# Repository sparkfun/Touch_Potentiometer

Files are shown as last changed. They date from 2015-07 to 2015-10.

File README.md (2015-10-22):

SparkFun Touch_Potentiometer
===================

SparkFun Touch Potentiometer

[*SparkFun Touch Potentiometer (PRT-13144)*](https://www.sparkfun.com/products/13144)

The Touch Potentiometer is a collaboration between DanJulioDesigns and SparkFun Electronics. The Touch Pot allows you to easily integrate a slide potentiometer into any project that requires such an interface, such as the volume control on a stereo. 

Repository Contents
-------------------

* **/Documentation** - Data sheets, additional product information
* **/Hardware** - Eagle design files (.brd, .sch)
* **/Production** - Production panel files (.brd)

Documentation
--------------
* **[Hookup Guide](https://learn.sparkfun.com/tutorials/touch-potentiometer-hookup-guide)** - Basic hookup guide for the SparkFun Touch Potentiometer.
* **[SparkFun Fritzing repo](https://github.com/sparkfun/Fritzing_Parts)** - Fritzing diagrams for SparkFun products.
* **[SparkFun 3D Model repo](https://github.com/sparkfun/3D_Models)** - 3D models of SparkFun products. 

Product Versions
----------------
* [*SEN-13144*](https://www.sparkfun.com/products/13144)

Version History
---------------

* [V_1.0.0](https://github.com/sparkfun/SparkFun_BME280_Breakout_Board/tree/V_1.0.0) - Public release.

License Information
-------------------

This product is _**open source**_! 

Please review the LICENSE.md file for license information. 

If you have any questions or concerns on licensing, please contact techsupport@sparkfun.com.

Distributed as-is; no warranty is given.

- Your friends at SparkFun.

_<COLLABORATION CREDIT>_

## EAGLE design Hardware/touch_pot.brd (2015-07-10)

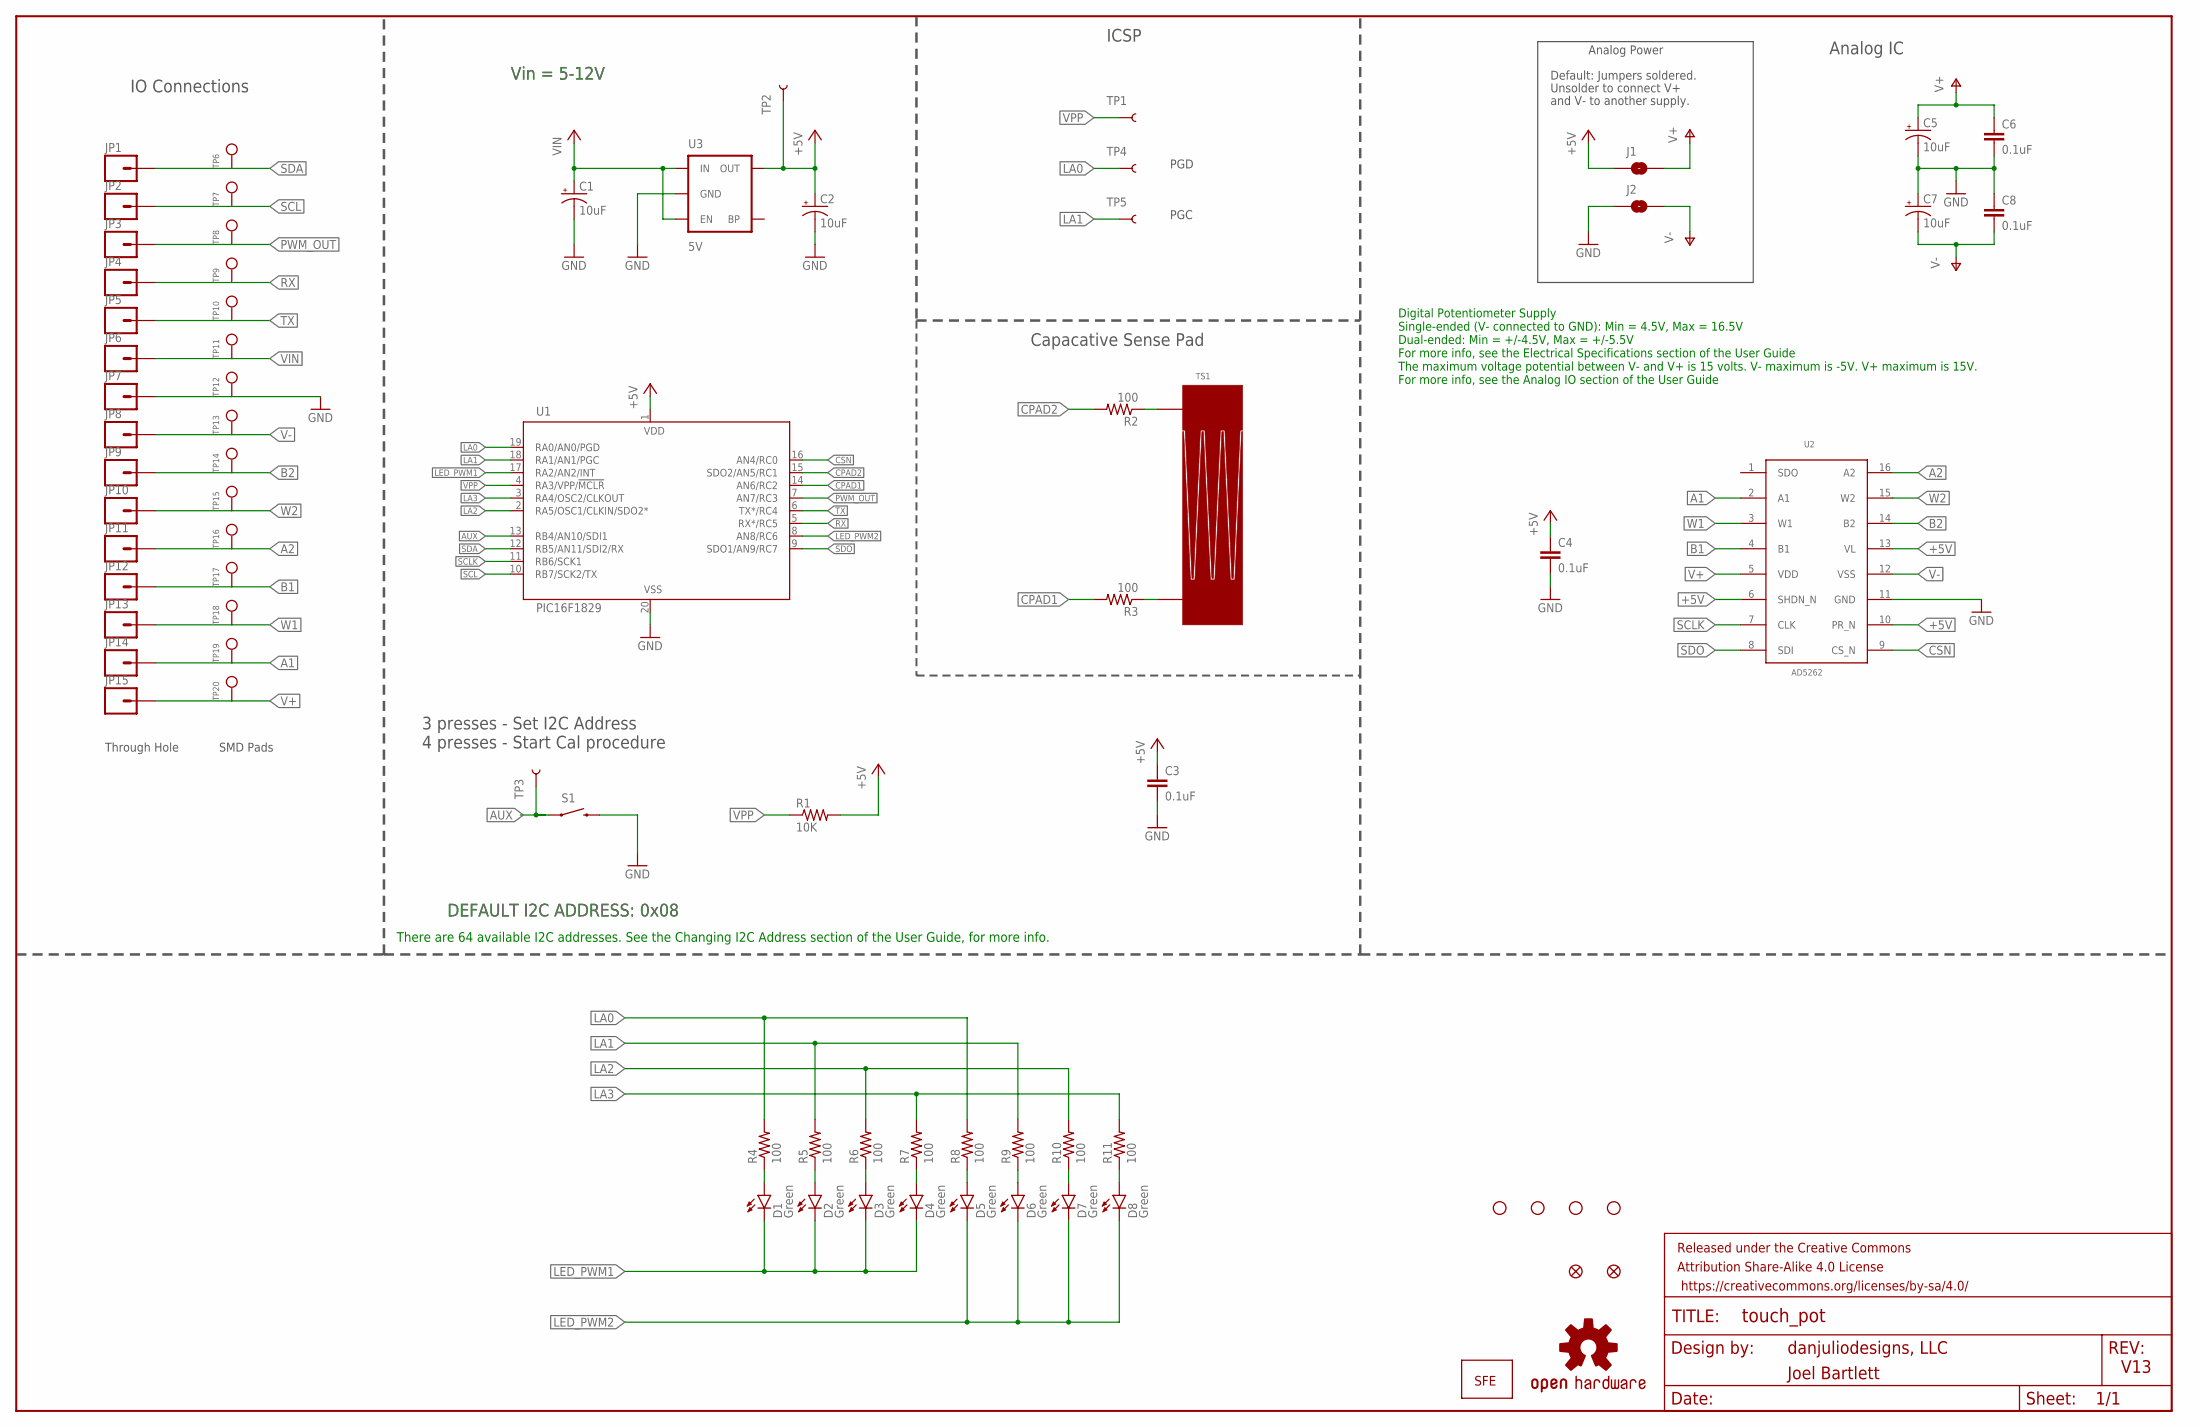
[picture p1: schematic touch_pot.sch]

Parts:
C1, C2, C5, C7: 10uF; EIA3216
C3, C4, C6, C8: 0.1uF; 0603-CAP
D1, D2, D3, D4, D5, D6, D7, D8: Green; LED-1206-BOTTOM
FID1, FID2: FIDUCIAL1X2; FIDUCIAL-1X2
FRAME3: FRAME-LEDGER; CREATIVE_COMMONS
J1, J2: SJCLOSED; SJ_2S
JP1, JP2, JP3, JP4, JP5, JP6, JP7, JP8, JP9, JP10, JP11, JP12, JP13, JP14, JP15: M01SMDNS; 1X01NS
R1: 10K; 0603-RES
R2, R3, R4, R5, R6, R7, R8, R9, R10, R11: 100; 0603-RES
S1: SWITCH-MOMENTARY-2SMD; TACTILE-SWITCH-SMD
STANDOFF1, STANDOFF2, STANDOFF3, STANDOFF4: STAND-OFFTIGHT; STAND-OFF-TIGHT
TP1, TP2, TP3, TP4, TP5: TEST-POINT3X4; PAD.03X.04
TP6, TP7, TP8, TP9, TP10, TP11, TP12, TP13, TP14, TP15, TP16, TP17, TP18, TP19, TP20: SINGLE_PADSMD; 2MM_SMD_PAD
TS1: 2CH_LINEAR_TOUCH; 2CH_48MM_LINEAR_TOUCH
U1: PIC16F1829; SSOP20
U2: AD5262; SSOP16
U3: 5V; SOT23-5
U$4: OSHW-LOGOM; OSHW-LOGO-M
U$5: SFE_LOGO_NAME_WEB; SFE-NEW-WEBLOGO

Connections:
+5V: C2.A (+), C3.1, C4.1, J1.1, R1.2, TP2.P$1, U1.1 (VDD), U2.6 (SHDN_N), U2.10 (PR_N), U2.13 (VL), U3.5 (OUT)
A1: JP14.1, TP19.P$1, U2.2 (A1)
A2: JP11.1, TP16.P$1, U2.16 (A2)
AUX: S1.1, TP3.P$1, U1.13 (RB4/AN10/SDI1)
B1: JP12.1, TP17.P$1, U2.4 (B1)
B2: JP9.1, TP14.P$1, U2.14 (B2)
CPAD1: R3.2, U1.14 (AN6/RC2)
CPAD2: R2.2, U1.15 (SDO2/AN5/RC1)
CSN: U1.16 (AN4/RC0), U2.9 (CS_N)
GND: C1.C (-), C2.C (-), C3.2, C4.2, C5.C (-), C6.2, C7.A (+), C8.1, J2.1, JP7.1, S1.3 (2), TP12.P$1, U1.20 (VSS), U2.11 (GND), U3.2 (GND)
LA0: R4.2, R8.2, TP4.P$1, U1.19 (RA0/AN0/PGD)
LA1: R5.2, R9.2, TP5.P$1, U1.18 (RA1/AN1/PGC)
LA2: R6.2, R10.2, U1.2 (RA5/OSC1/CLKIN/SDO2*)
LA3: R7.2, R11.2, U1.3 (RA4/OSC2/CLKOUT)
LED_PWM1: D1.C, D2.C, D3.C, D4.C, U1.17 (RA2/AN2/INT)
LED_PWM2: D5.C, D6.C, D7.C, D8.C, U1.8 (AN8/RC6)
unnamed: D1.A, R4.1
unnamed: D2.A, R5.1
unnamed: D3.A, R6.1
unnamed: D4.A, R7.1
unnamed: D5.A, R8.1
unnamed: D6.A, R9.1
unnamed: D7.A, R10.1
unnamed: D8.A, R11.1
unnamed: R2.1, TS1.P$2
unnamed: R3.1, TS1.P$1
PWM_OUT: JP3.1, TP8.P$1, U1.7 (AN7/RC3)
RX: JP4.1, TP9.P$1, U1.5 (RX*/RC5)
SCL: JP2.1, TP7.P$1, U1.10 (RB7/SCK2/TX)
SCLK: U1.11 (RB6/SCK1), U2.7 (CLK)
SDA: JP1.1, TP6.P$1, U1.12 (RB5/AN11/SDI2/RX)
SDO: U1.9 (SDO1/AN9/RC7), U2.8 (SDI)
TX: JP5.1, TP10.P$1, U1.6 (TX*/RC4)
V+: C5.A (+), C6.1, J1.2, JP15.1, TP20.P$1, U2.5 (VDD)
V-: C7.C (-), C8.2, J2.2, JP8.1, TP13.P$1, U2.12 (VSS)
VIN: C1.A (+), JP6.1, TP11.P$1, U3.1 (IN), U3.3 (EN)
VPP: R1.1, TP1.P$1, U1.4 (RA3/VPP/!MCLR)
W1: JP13.1, TP18.P$1, U2.3 (W1)
W2: JP10.1, TP15.P$1, U2.15 (W2)

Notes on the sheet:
danjuliodesigns, LLC
V13
3 presses - Set I2C Address 4 presses - Start Cal procedure
IO Connections
ICSP
Analog Power
Default: Jumpers soldered.
PGD
PGC
Unsolder to connect V+
and V- to another supply.
Through Hole
SMD Pads
Joel Bartlett
Analog IC
Vin = 5-12V
DEFAULT I2C ADDRESS: 0x08
Digital Potentiometer Supply Single-ended (V- connected to GND): Min = 4.5V, Max = 16.5V Dual-ended: Min = +/-4.5V, Max = +/-5.5V For more info, see the Electrical Specifications section of the User Guide The maximum voltage potential between V- and V+ is 15 volts. V- maximum is -5V. V+ maximum is 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
Capacative Sense Pad
There are 64 available I2C addresses. See the Changing I2C Address section of the User Guide, for more info.

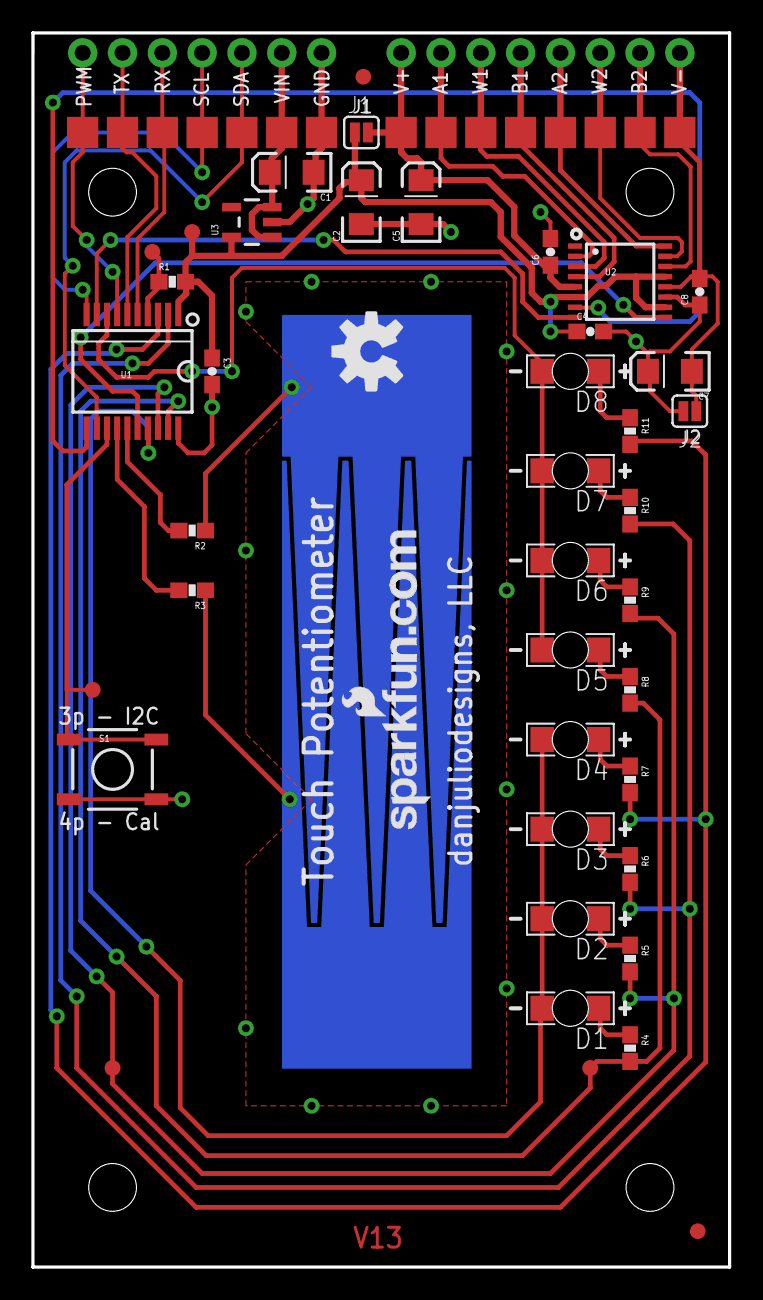
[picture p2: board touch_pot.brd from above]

Board: 2 copper layers, 44.5 x 78.7 mm, 78 parts (1 on the bottom side), 39 nets.

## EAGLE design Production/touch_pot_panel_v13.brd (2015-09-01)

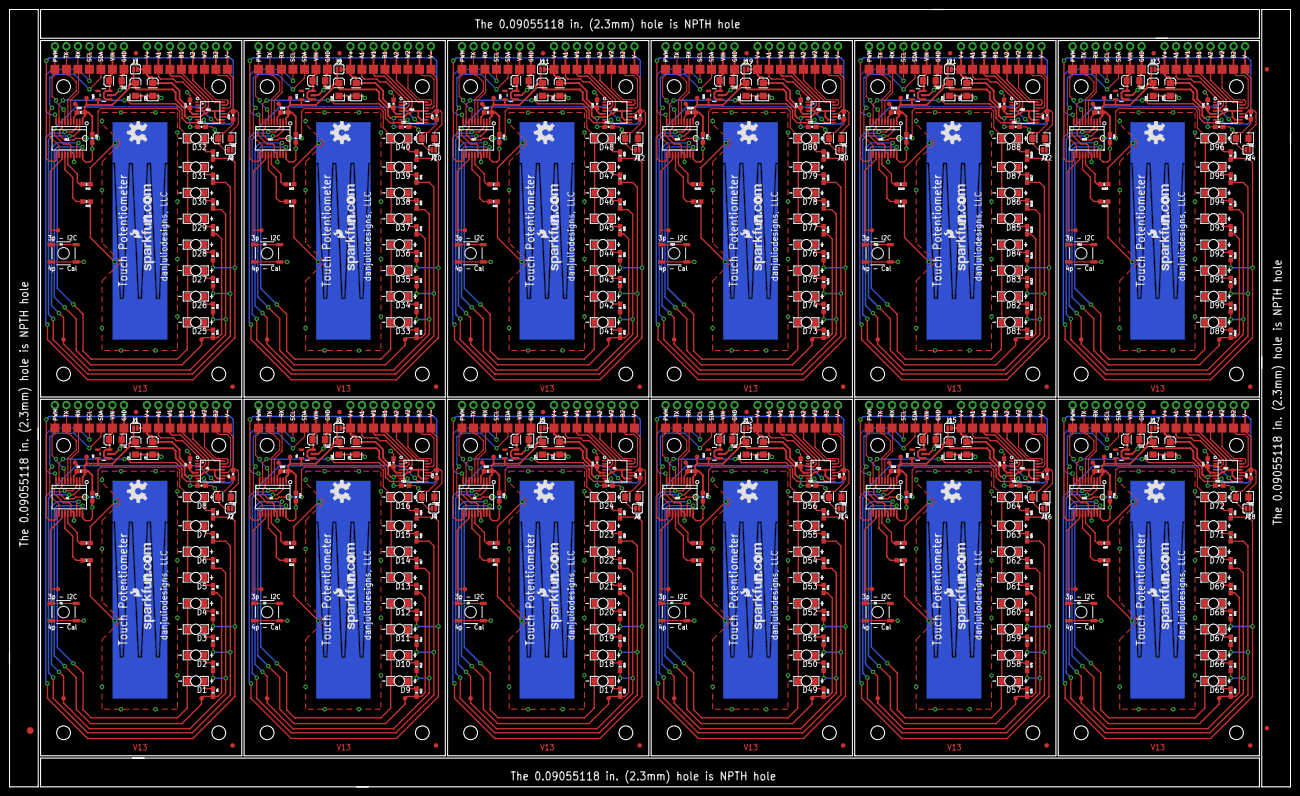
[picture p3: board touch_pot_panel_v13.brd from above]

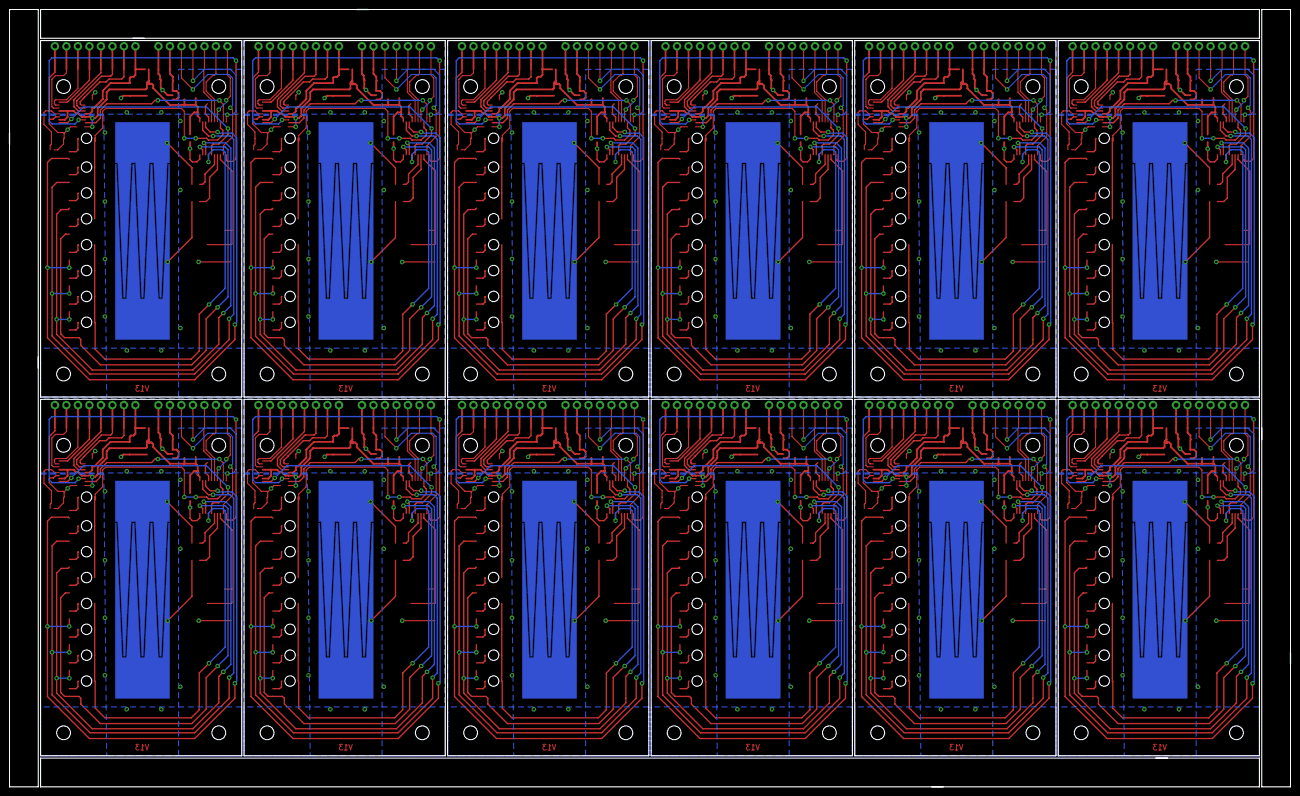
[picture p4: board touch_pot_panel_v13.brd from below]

Board: 2 copper layers, 283.0 x 171.7 mm, 927 parts (12 on the bottom side), 468 nets.

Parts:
C1, C2, C5, C7, C9, C10, C15, C16, C17, C18, C23, C24, C25, C26, C31, C32, C33, C34, C39, C40, C41, C42, C47, C48, C49, C50, C55, C56, C57, C58, C63, C64, C65, C66, C71, C72, C73, C74, C79, C80, C81, C82, C87, C88, C89, C90, C95, C96: 10uF; EIA3216
C3, C4, C6, C8, C11, C12, C13, C14, C19, C20, C21, C22, C27, C28, C29, C30, C35, C36, C37, C38, C43, C44, C45, C46, C51, C52, C53, C54, C59, C60, C61, C62, C67, C68, C69, C70, C75, C76, C77, C78, C83, C84, C85, C86, C91, C92, C93, C94: 0.1uF; 0603-CAP
D1, D2, D3, D4, D5, D6, D7, D8, D9, D10, D11, D12, D13, D14, D15, D16, D17, D18, D19, D20, D21, D22, D23, D24, D25, D26, D27, D28, D29, D30, D31, D32, D33, D34, D35, D36, D37, D38, D39, D40, D41, D42, D43, D44, D45, D46, D47, D48, D49, D50, D51, D52, D53, D54, D55, D56, D57, D58, D59, D60, D61, D62, D63, D64, D65, D66, D67, D68, D69, D70, D71, D72, D73, D74, D75, D76, D77, D78, D79, D80, D81, D82, D83, D84, D85, D86, D87, D88, D89, D90, D91, D92, D93, D94, D95, D96: Green; LED-1206-BOTTOM
E$1: FIDUCIAL-1.5X3
E$7, E$8: FIDUCIAL-1X2
FID1, FID2, FID3, FID4, FID5, FID6, FID7, FID8, FID9, FID10, FID11, FID12, FID13, FID14, FID15, FID16, FID17, FID18, FID19, FID20, FID21, FID22, FID23, FID24: FIDUCIAL1X2; FIDUCIAL-1X2
J1, J2, J3, J4, J5, J6, J7, J8, J9, J10, J11, J12, J13, J14, J15, J16, J17, J18, J19, J20, J21, J22, J23, J24: SJ_2S
JP1, JP2, JP3, JP4, JP5, JP6, JP7, JP8, JP9, JP10, JP11, JP12, JP13, JP14, JP15, JP16, JP17, JP18, JP19, JP20, JP21, JP22, JP23, JP24, JP25, JP26, JP27, JP28, JP29, JP30, JP31, JP32, JP33, JP34, JP35, JP36, JP37, JP38, JP39, JP40, JP41, JP42, JP43, JP44, JP45, JP46, JP47, JP48, JP49, JP50, JP51, JP52, JP53, JP54, JP55, JP56, JP57, JP58, JP59, JP60, JP61, JP62, JP63, JP64, JP65, JP66, JP67, JP68, JP69, JP70, JP71, JP72, JP73, JP74, JP75, JP76, JP77, JP78, JP79, JP80, JP81, JP82, JP83, JP84, JP85, JP86, JP87, JP88, JP89, JP90, JP91, JP92, JP93, JP94, JP95, JP96, JP97, JP98, JP99, JP100, JP101, JP102, JP103, JP104, JP105, JP106, JP107, JP108, JP109, JP110, JP111, JP112, JP113, JP114, JP115, JP116, JP117, JP118, JP119, JP120, JP121, JP122, JP123, JP124, JP125, JP126, JP127, JP128, JP129, JP130, JP131, JP132, JP133, JP134, JP135, JP136, JP137, JP138, JP139, JP140, JP141, JP142, JP143, JP144, JP145, JP146, JP147, JP148, JP149, JP150, JP151, JP152, JP153, JP154, JP155, JP156, JP157, JP158, JP159, JP160, JP161, JP162, JP163, JP164, JP165, JP166, JP167, JP168, JP169, JP170, JP171, JP172, JP173, JP174, JP175, JP176, JP177, JP178, JP179, JP180: 1X01NS
R1, R22, R33, R44, R55, R66, R77, R88, R99, R110, R121, R132: 10K; 0603-RES
R2, R3, R4, R5, R6, R7, R8, R9, R10, R11, R12, R13, R14, R15, R16, R17, R18, R19, R20, R21, R23, R24, R25, R26, R27, R28, R29, R30, R31, R32, R34, R35, R36, R37, R38, R39, R40, R41, R42, R43, R45, R46, R47, R48, R49, R50, R51, R52, R53, R54, R56, R57, R58, R59, R60, R61, R62, R63, R64, R65, R67, R68, R69, R70, R71, R72, R73, R74, R75, R76, R78, R79, R80, R81, R82, R83, R84, R85, R86, R87, R89, R90, R91, R92, R93, R94, R95, R96, R97, R98, R100, R101, R102, R103, R104, R105, R106, R107, R108, R109, R111, R112, R113, R114, R115, R116, R117, R118, R119, R120, R122, R123, R124, R125, R126, R127, R128, R129, R130, R131: 100; 0603-RES
S1, S2, S3, S4, S5, S6, S7, S8, S9, S10, S11, S12: TACTILE-SWITCH-SMD
STANDOFF1, STANDOFF2, STANDOFF3, STANDOFF4, STANDOFF5, STANDOFF6, STANDOFF7, STANDOFF8, STANDOFF9, STANDOFF10, STANDOFF11, STANDOFF12, STANDOFF13, STANDOFF14, STANDOFF15, STANDOFF16, STANDOFF17, STANDOFF18, STANDOFF19, STANDOFF20, STANDOFF21, STANDOFF22, STANDOFF23, STANDOFF24, STANDOFF25, STANDOFF26, STANDOFF27, STANDOFF28, STANDOFF29, STANDOFF30, STANDOFF31, STANDOFF32, STANDOFF33, STANDOFF34, STANDOFF35, STANDOFF36, STANDOFF37, STANDOFF38, STANDOFF39, STANDOFF40, STANDOFF41, STANDOFF42, STANDOFF43, STANDOFF44, STANDOFF45, STANDOFF46, STANDOFF47, STANDOFF48: STAND-OFFTIGHT; STAND-OFF-TIGHT
TP1, TP2, TP3, TP4, TP5, TP36, TP37, TP38, TP39, TP40, TP56, TP57, TP58, TP59, TP60, TP76, TP77, TP78, TP79, TP80, TP96, TP97, TP98, TP99, TP100, TP116, TP117, TP118, TP119, TP120, TP136, TP137, TP138, TP139, TP140, TP156, TP157, TP158, TP159, TP160, TP176, TP177, TP178, TP179, TP180, TP196, TP197, TP198, TP199, TP200, TP216, TP217, TP218, TP219, TP220, TP236, TP237, TP238, TP239, TP240: PAD.03X.04
TP6, TP7, TP8, TP9, TP10, TP11, TP12, TP13, TP14, TP15, TP16, TP17, TP18, TP19, TP20, TP21, TP22, TP23, TP24, TP25, TP26, TP27, TP28, TP29, TP30, TP31, TP32, TP33, TP34, TP35, TP41, TP42, TP43, TP44, TP45, TP46, TP47, TP48, TP49, TP50, TP51, TP52, TP53, TP54, TP55, TP61, TP62, TP63, TP64, TP65, TP66, TP67, TP68, TP69, TP70, TP71, TP72, TP73, TP74, TP75, TP81, TP82, TP83, TP84, TP85, TP86, TP87, TP88, TP89, TP90, TP91, TP92, TP93, TP94, TP95, TP101, TP102, TP103, TP104, TP105, TP106, TP107, TP108, TP109, TP110, TP111, TP112, TP113, TP114, TP115, TP121, TP122, TP123, TP124, TP125, TP126, TP127, TP128, TP129, TP130, TP131, TP132, TP133, TP134, TP135, TP141, TP142, TP143, TP144, TP145, TP146, TP147, TP148, TP149, TP150, TP151, TP152, TP153, TP154, TP155, TP161, TP162, TP163, TP164, TP165, TP166, TP167, TP168, TP169, TP170, TP171, TP172, TP173, TP174, TP175, TP181, TP182, TP183, TP184, TP185, TP186, TP187, TP188, TP189, TP190, TP191, TP192, TP193, TP194, TP195, TP201, TP202, TP203, TP204, TP205, TP206, TP207, TP208, TP209, TP210, TP211, TP212, TP213, TP214, TP215, TP221, TP222, TP223, TP224, TP225, TP226, TP227, TP228, TP229, TP230, TP231, TP232, TP233, TP234, TP235: 2MM_SMD_PAD
TS1, TS2, TS3, TS4, TS5, TS6, TS7, TS8, TS9, TS10, TS11, TS12: 2CH_48MM_LINEAR_TOUCH
U1, U5, U8, U11, U14, U17, U20, U23, U26, U29, U32, U35: PIC16F1829; SSOP20
U2, U6, U9, U12, U15, U18, U21, U24, U27, U30, U33, U36: AD5262; SSOP16
U3, U4, U7, U10, U13, U16, U19, U22, U25, U28, U31, U34: 5V; SOT23-5
U$1, U$3, U$4, U$7, U$9, U$11, U$13, U$15, U$17, U$19, U$21, U$23: OSHW-LOGOM; OSHW-LOGO-M
U$2, U$5, U$6, U$8, U$10, U$12, U$14, U$16, U$18, U$20, U$22, U$24: SFE_LOGO_NAME_WEB; SFE-NEW-WEBLOGO

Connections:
+5V: C2.A, C3.1, C4.1, J1.1, R1.2, TP2.P$1, U1.1, U2.6, U2.10, U2.13, U3.5
+5V1: C13.1, C14.1, C16.A, J3.1, R22.2, TP36.P$1, U4.5, U5.1, U6.6, U6.10, U6.13
+5V2: C21.1, C22.1, C24.A, J5.1, R33.2, TP56.P$1, U7.5, U8.1, U9.6, U9.10, U9.13
+5V3: C29.1, C30.1, C32.A, J7.1, R44.2, TP76.P$1, U10.5, U11.1, U12.6, U12.10, U12.13
+5V4: C37.1, C38.1, C40.A, J9.1, R55.2, TP96.P$1, U13.5, U14.1, U15.6, U15.10, U15.13
+5V5: C45.1, C46.1, C48.A, J11.1, R66.2, TP116.P$1, U16.5, U17.1, U18.6, U18.10, U18.13
+5V6: C53.1, C54.1, C56.A, J13.1, R77.2, TP136.P$1, U19.5, U20.1, U21.6, U21.10, U21.13
+5V7: C61.1, C62.1, C64.A, J15.1, R88.2, TP156.P$1, U22.5, U23.1, U24.6, U24.10, U24.13
+5V8: C69.1, C70.1, C72.A, J17.1, R99.2, TP176.P$1, U25.5, U26.1, U27.6, U27.10, U27.13
+5V9: C77.1, C78.1, C80.A, J19.1, R110.2, TP196.P$1, U28.5, U29.1, U30.6, U30.10, U30.13
+5V10: C85.1, C86.1, C88.A, J21.1, R121.2, TP216.P$1, U31.5, U32.1, U33.6, U33.10, U33.13
+5V11: C93.1, C94.1, C96.A, J23.1, R132.2, TP236.P$1, U34.5, U35.1, U36.6, U36.10, U36.13
A1: JP14.1, TP19.P$1, U2.2
A2: JP11.1, TP16.P$1, U2.16
A3: JP29.1, TP34.P$1, U6.2
A4: JP26.1, TP31.P$1, U6.16
A5: JP44.1, TP54.P$1, U9.2
A6: JP41.1, TP51.P$1, U9.16
A7: JP59.1, TP74.P$1, U12.2
A8: JP56.1, TP71.P$1, U12.16
A9: JP74.1, TP94.P$1, U15.2
A10: JP71.1, TP91.P$1, U15.16
A11: JP89.1, TP114.P$1, U18.2
A12: JP86.1, TP111.P$1, U18.16
A13: JP104.1, TP134.P$1, U21.2
A14: JP101.1, TP131.P$1, U21.16
A15: JP119.1, TP154.P$1, U24.2
A16: JP116.1, TP151.P$1, U24.16
A17: JP134.1, TP174.P$1, U27.2
A18: JP131.1, TP171.P$1, U27.16
A19: JP149.1, TP194.P$1, U30.2
A20: JP146.1, TP191.P$1, U30.16
A21: JP164.1, TP214.P$1, U33.2
A22: JP161.1, TP211.P$1, U33.16
A23: JP179.1, TP234.P$1, U36.2
A24: JP176.1, TP231.P$1, U36.16
AUX: S1.1, TP3.P$1, U1.13
AUX1: S2.1, TP37.P$1, U5.13
AUX2: S3.1, TP57.P$1, U8.13
AUX3: S4.1, TP77.P$1, U11.13
AUX4: S5.1, TP97.P$1, U14.13
AUX5: S6.1, TP117.P$1, U17.13
AUX6: S7.1, TP137.P$1, U20.13
AUX7: S8.1, TP157.P$1, U23.13
AUX8: S9.1, TP177.P$1, U26.13
AUX9: S10.1, TP197.P$1, U29.13
AUX10: S11.1, TP217.P$1, U32.13
AUX11: S12.1, TP237.P$1, U35.13
B1: JP12.1, TP17.P$1, U2.4
B2: JP9.1, TP14.P$1, U2.14
B3: JP27.1, TP32.P$1, U6.4
B4: JP24.1, TP29.P$1, U6.14
B5: JP42.1, TP52.P$1, U9.4
B6: JP39.1, TP49.P$1, U9.14
B7: JP57.1, TP72.P$1, U12.4
B8: JP54.1, TP69.P$1, U12.14
B9: JP72.1, TP92.P$1, U15.4
B10: JP69.1, TP89.P$1, U15.14
B11: JP87.1, TP112.P$1, U18.4
B12: JP84.1, TP109.P$1, U18.14
B13: JP102.1, TP132.P$1, U21.4
B14: JP99.1, TP129.P$1, U21.14
B15: JP117.1, TP152.P$1, U24.4
B16: JP114.1, TP149.P$1, U24.14
B17: JP132.1, TP172.P$1, U27.4
B18: JP129.1, TP169.P$1, U27.14
B19: JP147.1, TP192.P$1, U30.4
B20: JP144.1, TP189.P$1, U30.14
B21: JP162.1, TP212.P$1, U33.4
B22: JP159.1, TP209.P$1, U33.14
B23: JP177.1, TP232.P$1, U36.4
B24: JP174.1, TP229.P$1, U36.14
CPAD1: R3.2, U1.14
CPAD2: R2.2, U1.15
CPAD3: R21.2, U5.14
CPAD4: R20.2, U5.15
CPAD5: R32.2, U8.14
CPAD6: R31.2, U8.15
CPAD7: R43.2, U11.14
CPAD8: R42.2, U11.15
CPAD9: R54.2, U14.14
CPAD10: R53.2, U14.15
CPAD11: R65.2, U17.14
CPAD12: R64.2, U17.15
CPAD13: R76.2, U20.14
CPAD14: R75.2, U20.15
CPAD15: R87.2, U23.14
CPAD16: R86.2, U23.15
CPAD17: R98.2, U26.14
CPAD18: R97.2, U26.15
CPAD19: R109.2, U29.14
CPAD20: R108.2, U29.15
CPAD21: R120.2, U32.14
CPAD22: R119.2, U32.15
CPAD23: R131.2, U35.14
CPAD24: R130.2, U35.15
CSN: U1.16, U2.9
CSN1: U5.16, U6.9
CSN2: U8.16, U9.9
CSN3: U11.16, U12.9
CSN4: U14.16, U15.9
CSN5: U17.16, U18.9
CSN6: U20.16, U21.9
CSN7: U23.16, U24.9
CSN8: U26.16, U27.9
CSN9: U29.16, U30.9
CSN10: U32.16, U33.9
CSN11: U35.16, U36.9
GND: C1.C, C2.C, C3.2, C4.2, C5.C, C6.2, C7.A, C8.1, J2.1, JP7.1, S1.3, TP12.P$1, U1.20, U2.11, U3.2
GND1: C9.C, C10.A, C11.2, C12.1, C13.2, C14.2, C15.C, C16.C, J4.1, JP22.1, S2.3, TP27.P$1, U4.2, U5.20, U6.11
GND2: C17.C, C18.A, C19.2, C20.1, C21.2, C22.2, C23.C, C24.C, J6.1, JP37.1, S3.3, TP47.P$1, U7.2, U8.20, U9.11
GND3: C25.C, C26.A, C27.2, C28.1, C29.2, C30.2, C31.C, C32.C, J8.1, JP52.1, S4.3, TP67.P$1, U10.2, U11.20, U12.11
GND4: C33.C, C34.A, C35.2, C36.1, C37.2, C38.2, C39.C, C40.C, J10.1, JP67.1, S5.3, TP87.P$1, U13.2, U14.20, U15.11
GND5: C41.C, C42.A, C43.2, C44.1, C45.2, C46.2, C47.C, C48.C, J12.1, JP82.1, S6.3, TP107.P$1, U16.2, U17.20, U18.11
GND6: C49.C, C50.A, C51.2, C52.1, C53.2, C54.2, C55.C, C56.C, J14.1, JP97.1, S7.3, TP127.P$1, U19.2, U20.20, U21.11
GND7: C57.C, C58.A, C59.2, C60.1, C61.2, C62.2, C63.C, C64.C, J16.1, JP112.1, S8.3, TP147.P$1, U22.2, U23.20, U24.11
GND8: C65.C, C66.A, C67.2, C68.1, C69.2, C70.2, C71.C, C72.C, J18.1, JP127.1, S9.3, TP167.P$1, U25.2, U26.20, U27.11
GND9: C73.C, C74.A, C75.2, C76.1, C77.2, C78.2, C79.C, C80.C, J20.1, JP142.1, S10.3, TP187.P$1, U28.2, U29.20, U30.11
GND10: C81.C, C82.A, C83.2, C84.1, C85.2, C86.2, C87.C, C88.C, J22.1, JP157.1, S11.3, TP207.P$1, U31.2, U32.20, U33.11
GND11: C89.C, C90.A, C91.2, C92.1, C93.2, C94.2, C95.C, C96.C, J24.1, JP172.1, S12.3, TP227.P$1, U34.2, U35.20, U36.11
LA0: R4.2, R8.2, TP4.P$1, U1.19
LA1: R5.2, R9.2, TP5.P$1, U1.18
LA2: R6.2, R10.2, U1.2
LA3: R7.2, R11.2, U1.3
LA4: R14.2, R18.2, U5.2
LA5: R15.2, R19.2, U5.3
LA6: R13.2, R17.2, TP40.P$1, U5.18
LA7: R12.2, R16.2, TP39.P$1, U5.19
LA8: R25.2, R29.2, U8.2
LA9: R26.2, R30.2, U8.3
LA10: R24.2, R28.2, TP60.P$1, U8.18
LA11: R23.2, R27.2, TP59.P$1, U8.19
LA12: R36.2, R40.2, U11.2
LA13: R37.2, R41.2, U11.3
LA14: R35.2, R39.2, TP80.P$1, U11.18
LA15: R34.2, R38.2, TP79.P$1, U11.19
LA16: R47.2, R51.2, U14.2
LA17: R48.2, R52.2, U14.3
LA18: R46.2, R50.2, TP100.P$1, U14.18
LA19: R45.2, R49.2, TP99.P$1, U14.19
LA20: R58.2, R62.2, U17.2
LA21: R59.2, R63.2, U17.3
LA22: R57.2, R61.2, TP120.P$1, U17.18
LA23: R56.2, R60.2, TP119.P$1, U17.19
LA24: R69.2, R73.2, U20.2
LA25: R70.2, R74.2, U20.3
LA26: R68.2, R72.2, TP140.P$1, U20.18
LA27: R67.2, R71.2, TP139.P$1, U20.19
LA28: R80.2, R84.2, U23.2
LA29: R81.2, R85.2, U23.3
LA30: R79.2, R83.2, TP160.P$1, U23.18
LA31: R78.2, R82.2, TP159.P$1, U23.19
LA32: R91.2, R95.2, U26.2
LA33: R92.2, R96.2, U26.3
LA34: R90.2, R94.2, TP180.P$1, U26.18
LA35: R89.2, R93.2, TP179.P$1, U26.19
LA36: R102.2, R106.2, U29.2
LA37: R103.2, R107.2, U29.3
LA38: R101.2, R105.2, TP200.P$1, U29.18
LA39: R100.2, R104.2, TP199.P$1, U29.19
LA40: R113.2, R117.2, U32.2
LA41: R114.2, R118.2, U32.3
LA42: R112.2, R116.2, TP220.P$1, U32.18
LA43: R111.2, R115.2, TP219.P$1, U32.19
LA44: R124.2, R128.2, U35.2
LA45: R125.2, R129.2, U35.3
LA46: R123.2, R127.2, TP240.P$1, U35.18
LA47: R122.2, R126.2, TP239.P$1, U35.19
LED_PWM1: D1.C, D2.C, D3.C, D4.C, U1.17
LED_PWM2: D5.C, D6.C, D7.C, D8.C, U1.8
LED_PWM3: D9.C, D10.C, D11.C, D12.C, U5.17
LED_PWM4: D13.C, D14.C, D15.C, D16.C, U5.8
LED_PWM5: D17.C, D18.C, D19.C, D20.C, U8.17
LED_PWM6: D21.C, D22.C, D23.C, D24.C, U8.8
LED_PWM7: D25.C, D26.C, D27.C, D28.C, U11.17
LED_PWM8: D29.C, D30.C, D31.C, D32.C, U11.8
LED_PWM9: D33.C, D34.C, D35.C, D36.C, U14.17
LED_PWM10: D37.C, D38.C, D39.C, D40.C, U14.8
LED_PWM11: D41.C, D42.C, D43.C, D44.C, U17.17
LED_PWM12: D45.C, D46.C, D47.C, D48.C, U17.8
LED_PWM13: D49.C, D50.C, D51.C, D52.C, U20.17
LED_PWM14: D53.C, D54.C, D55.C, D56.C, U20.8
LED_PWM15: D57.C, D58.C, D59.C, D60.C, U23.17
LED_PWM16: D61.C, D62.C, D63.C, D64.C, U23.8
LED_PWM17: D65.C, D66.C, D67.C, D68.C, U26.17
LED_PWM18: D69.C, D70.C, D71.C, D72.C, U26.8
LED_PWM19: D73.C, D74.C, D75.C, D76.C, U29.17
LED_PWM20: D77.C, D78.C, D79.C, D80.C, U29.8
LED_PWM21: D81.C, D82.C, D83.C, D84.C, U32.17
LED_PWM22: D85.C, D86.C, D87.C, D88.C, U32.8
LED_PWM23: D89.C, D90.C, D91.C, D92.C, U35.17
LED_PWM24: D93.C, D94.C, D95.C, D96.C, U35.8
unnamed: D1.A, R4.1
unnamed: D2.A, R5.1
unnamed: D3.A, R6.1
unnamed: D4.A, R7.1
unnamed: D5.A, R8.1
unnamed: D6.A, R9.1
unnamed: D7.A, R10.1
unnamed: D8.A, R11.1
unnamed: R20.1, TS2.P$2
unnamed: R21.1, TS2.P$1
unnamed: D9.A, R12.1
unnamed: D10.A, R13.1
unnamed: D11.A, R14.1
unnamed: D12.A, R15.1
unnamed: D13.A, R16.1
unnamed: D14.A, R17.1
unnamed: D15.A, R18.1
unnamed: D16.A, R19.1
unnamed: R31.1, TS3.P$2
unnamed: R32.1, TS3.P$1
unnamed: D17.A, R23.1
unnamed: D18.A, R24.1
unnamed: D19.A, R25.1
unnamed: D20.A, R26.1
unnamed: D21.A, R27.1
unnamed: D22.A, R28.1
unnamed: D23.A, R29.1
unnamed: D24.A, R30.1
unnamed: R42.1, TS4.P$2
unnamed: R43.1, TS4.P$1
unnamed: R2.1, TS1.P$2
unnamed: R3.1, TS1.P$1
unnamed: D25.A, R34.1
unnamed: D26.A, R35.1
unnamed: D27.A, R36.1
unnamed: D28.A, R37.1
unnamed: D29.A, R38.1
unnamed: D30.A, R39.1
unnamed: D31.A, R40.1
unnamed: D32.A, R41.1
unnamed: R53.1, TS5.P$2
unnamed: R54.1, TS5.P$1
unnamed: D33.A, R45.1
unnamed: D34.A, R46.1
unnamed: D35.A, R47.1
unnamed: D36.A, R48.1
unnamed: D37.A, R49.1
unnamed: D38.A, R50.1
unnamed: D39.A, R51.1
unnamed: D40.A, R52.1
unnamed: R64.1, TS6.P$2
unnamed: R65.1, TS6.P$1
unnamed: D41.A, R56.1
unnamed: D42.A, R57.1
unnamed: D43.A, R58.1
unnamed: D44.A, R59.1
unnamed: D45.A, R60.1
unnamed: D46.A, R61.1
unnamed: D47.A, R62.1
unnamed: D48.A, R63.1
unnamed: R75.1, TS7.P$2
unnamed: R76.1, TS7.P$1
unnamed: D49.A, R67.1
unnamed: D50.A, R68.1
unnamed: D51.A, R69.1
unnamed: D52.A, R70.1
unnamed: D53.A, R71.1
unnamed: D54.A, R72.1
unnamed: D55.A, R73.1
unnamed: D56.A, R74.1
unnamed: R86.1, TS8.P$2
unnamed: R87.1, TS8.P$1
unnamed: D57.A, R78.1
unnamed: D58.A, R79.1
unnamed: D59.A, R80.1
unnamed: D60.A, R81.1
unnamed: D61.A, R82.1
unnamed: D62.A, R83.1
unnamed: D63.A, R84.1
unnamed: D64.A, R85.1
unnamed: R97.1, TS9.P$2
unnamed: R98.1, TS9.P$1
unnamed: D65.A, R89.1
unnamed: D66.A, R90.1
unnamed: D67.A, R91.1
unnamed: D68.A, R92.1
unnamed: D69.A, R93.1
unnamed: D70.A, R94.1
unnamed: D71.A, R95.1
unnamed: D72.A, R96.1
unnamed: R108.1, TS10.P$2
unnamed: R109.1, TS10.P$1
unnamed: D73.A, R100.1
unnamed: D74.A, R101.1
unnamed: D75.A, R102.1
unnamed: D76.A, R103.1
unnamed: D77.A, R104.1
unnamed: D78.A, R105.1
unnamed: D79.A, R106.1
unnamed: D80.A, R107.1
unnamed: R119.1, TS11.P$2
unnamed: R120.1, TS11.P$1
unnamed: D81.A, R111.1
unnamed: D82.A, R112.1
unnamed: D83.A, R113.1
unnamed: D84.A, R114.1
unnamed: D85.A, R115.1
unnamed: D86.A, R116.1
unnamed: D87.A, R117.1
unnamed: D88.A, R118.1
unnamed: R130.1, TS12.P$2
unnamed: R131.1, TS12.P$1
unnamed: D89.A, R122.1
unnamed: D90.A, R123.1
unnamed: D91.A, R124.1
unnamed: D92.A, R125.1
unnamed: D93.A, R126.1
unnamed: D94.A, R127.1
unnamed: D95.A, R128.1
unnamed: D96.A, R129.1
PWM_OUT: JP3.1, TP8.P$1, U1.7
PWM_OUT1: JP18.1, TP23.P$1, U5.7
PWM_OUT2: JP33.1, TP43.P$1, U8.7
PWM_OUT3: JP48.1, TP63.P$1, U11.7
PWM_OUT4: JP63.1, TP83.P$1, U14.7
PWM_OUT5: JP78.1, TP103.P$1, U17.7
PWM_OUT6: JP93.1, TP123.P$1, U20.7
PWM_OUT7: JP108.1, TP143.P$1, U23.7
PWM_OUT8: JP123.1, TP163.P$1, U26.7
PWM_OUT9: JP138.1, TP183.P$1, U29.7
PWM_OUT10: JP153.1, TP203.P$1, U32.7
PWM_OUT11: JP168.1, TP223.P$1, U35.7
RX: JP4.1, TP9.P$1, U1.5
RX1: JP19.1, TP24.P$1, U5.5
RX2: JP34.1, TP44.P$1, U8.5
RX3: JP49.1, TP64.P$1, U11.5
RX4: JP64.1, TP84.P$1, U14.5
RX5: JP79.1, TP104.P$1, U17.5
RX6: JP94.1, TP124.P$1, U20.5
RX7: JP109.1, TP144.P$1, U23.5
RX8: JP124.1, TP164.P$1, U26.5
RX9: JP139.1, TP184.P$1, U29.5
RX10: JP154.1, TP204.P$1, U32.5
RX11: JP169.1, TP224.P$1, U35.5
SCL: JP2.1, TP7.P$1, U1.10
SCL1: JP17.1, TP22.P$1, U5.10
SCL2: JP32.1, TP42.P$1, U8.10
SCL3: JP47.1, TP62.P$1, U11.10
SCL4: JP62.1, TP82.P$1, U14.10
SCL5: JP77.1, TP102.P$1, U17.10
SCL6: JP92.1, TP122.P$1, U20.10
SCL7: JP107.1, TP142.P$1, U23.10
SCL8: JP122.1, TP162.P$1, U26.10
SCL9: JP137.1, TP182.P$1, U29.10
SCL10: JP152.1, TP202.P$1, U32.10
SCL11: JP167.1, TP222.P$1, U35.10
SCLK: U1.11, U2.7
SCLK1: U5.11, U6.7
SCLK2: U8.11, U9.7
SCLK3: U11.11, U12.7
SCLK4: U14.11, U15.7
SCLK5: U17.11, U18.7
SCLK6: U20.11, U21.7
SCLK7: U23.11, U24.7
SCLK8: U26.11, U27.7
SCLK9: U29.11, U30.7
SCLK10: U32.11, U33.7
SCLK11: U35.11, U36.7
SDA: JP1.1, TP6.P$1, U1.12
SDA1: JP16.1, TP21.P$1, U5.12
SDA2: JP31.1, TP41.P$1, U8.12
SDA3: JP46.1, TP61.P$1, U11.12
SDA4: JP61.1, TP81.P$1, U14.12
SDA5: JP76.1, TP101.P$1, U17.12
SDA6: JP91.1, TP121.P$1, U20.12
SDA7: JP106.1, TP141.P$1, U23.12
SDA8: JP121.1, TP161.P$1, U26.12
SDA9: JP136.1, TP181.P$1, U29.12
SDA10: JP151.1, TP201.P$1, U32.12
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

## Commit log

2014-06-13 Initial Commit
    Committing files given to me by Dan Julio. Will be working to scrub the
    design, switch out parts for SFE parts, and figure out what parts will
    need to be ordered and added to inventory.
    [touch_pot_test.brd, touch_pot_test.sch]
2014-06-13 Fixed Frame
    Added the correct frame on schematic and moved around testbed files
    [touch_pot.brd, touch_pot.sch, touch_pot_test.brd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]
2014-07-02 First Round of changes before Protos
    Changed Dimension thickness
    Changed silk ratio
    Added designed by name
    Bumped via size up to 0.020
    Added actual stand-offs instead of drill hits
    Labeled push button
    [touch_pot.brd, touch_pot.sch]
2014-08-30 Work in progress
    rerouting for fourth standoff hole
    [touch_pot.brd, touch_pot.sch]
2014-09-22 Last commit before protos
    Finally rerouted to add space for fourth stand-off hole.
    [touch_pot.brd]
2014-10-31 Fixing weird file glitchs
    [touch_pot.brd, touch_pot.sch]
2014-11-10 2nd Round of Protos
    Added a few test points, moved a cap closer to analog IC, moved button
    down to avoid touching resistors.
    [touch_pot.brd, touch_pot.sch]
2014-11-13 Final commit before 2nd round of protos - 4 real
    made all test points the same size, trace clean up, moved filtering cap
    as close as possible.
    [touch_pot.brd, touch_pot.sch]
2014-11-13 Schematic Cleanup
    added flags, added I2C and VIN Info, general cleanup
    [touch_pot.brd, touch_pot.sch]
2014-11-21 Changed all parts to SFE parts with SKUs
    Changed all parts to SFE parts with SKUs
    [touch_pot.brd, touch_pot.sch]
2014-11-26 Last push before second round of protos 4 Realz
    Lots of QC checklist changes, added parts to SFE library,
    isolate, schematic cleanup, added all SFE parts with SKUs.
    [touch_pot.brd, touch_pot.sch]
2015-01-05 Changed pinout to standard I2C pinout
    Changed pinout to standard I2C pinout
    [touch_pot.brd, touch_pot.sch]
2015-01-07 Ready for Reds
    Added note about Non-plated Thru Holes on the bottom-mounted LEDs,
    added note about I2C addressing, added note about maximum and min.
    voltages on V+ and V-, moved VPP test point ever so slightly, added
    polarity silk to bottom-mounted LEDs, added note in Sparkle about BLACK
    SOLDERMASK.
    [touch_pot.brd, touch_pot.sch]
2015-01-21 replaced fids with SFE fids
    [touch_pot.brd, touch_pot.sch, touch_pot_test.brd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]
2015-01-21 created panel v12
    [touch_pot_Panel_v12.brd]
2015-05-08 V13 Changes
    Adjusted headers to fit on breadboard. Minor rerouting. Moved silk.
    [touch_pot.brd, touch_pot.sch]
2015-05-08 V13
    v13
    [touch_pot.brd, touch_pot.sch]
2015-05-29 Adjusting PTH for breadboard
    Adjusted the PTH holes to fit into a breadboard. Dan has completed
    major firmware updates. Can now calibrate ion the fly with push button.
    Moved PTH holes to end of PCB and silk in-between PTH and SMD pads.
    [touch_pot.brd]
2015-06-02 Clean-up, change button text
    Moved traces away from hole, deleted unused ground traces, resized one
    trace, changed button text for both i2c and cal.
    [touch_pot.brd, touch_pot.sch]
2015-07-10 Last QC Check changes
    Minor changes based on QC Checklist.
    [touch_pot.brd, touch_pot.sch]
2015-09-01 created panel v13
    [touch_pot_Panel_v12.brd, touch_pot_panel_v13.brd, touch_pot_test.brd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]
2015-09-01 removed odd ground line
    [touch_pot_panel_v13.brd]

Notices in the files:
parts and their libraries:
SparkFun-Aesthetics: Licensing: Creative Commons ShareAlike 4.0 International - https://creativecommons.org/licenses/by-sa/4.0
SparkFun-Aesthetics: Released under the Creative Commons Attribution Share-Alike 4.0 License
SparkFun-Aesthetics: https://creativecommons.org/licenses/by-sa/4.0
